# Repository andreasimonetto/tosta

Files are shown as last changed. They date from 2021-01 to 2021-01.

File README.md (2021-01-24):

# Tosta

Tosta is a **low-power terminal interface module** built around the [STM32G030](docs/STM32G0x0.pdf) microcontroller. The module features:

- 48x84 monochrome pixel matrix (Nokia 5510 LCD using [PCD8544](docs/PCD8544.pdf) controller)
- configurable dimmable backlight
- configurable display standby timer
- a rotary encoder with central switch
- a D-Pad joystick with central switch
- 4 tactile switches
- a speaker
- an UART interface @ 115200 baud/s
- an I2C slave interface @ 400KHz (address 0x7D)
- 150uA consumption in standby mode

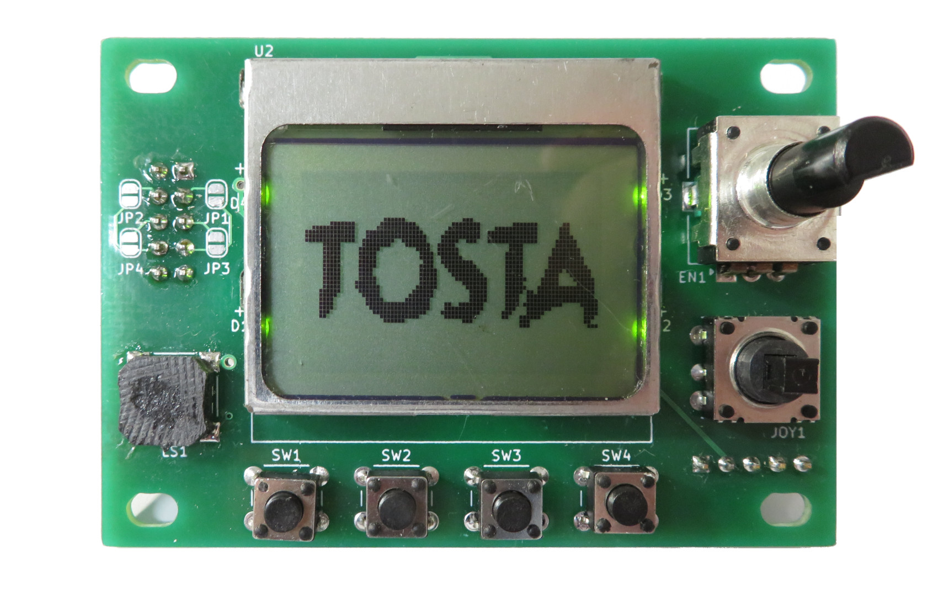
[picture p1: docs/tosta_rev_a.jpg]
Board


## User guide

The main communication interface (characters based) is UART @ 115200 baud/s.
I2C (binary based) is used for fast display update among other things.

### UART Inputs

When the module receive an input, it send a corresponding command character as
follows:

Event                        | Hex  | Char
---------------------------- | ---- | ----
SW1 pressed                  | 0x41 | A
SW1 released                 | 0x61 | a
SW2 pressed                  | 0x42 | B
SW2 released                 | 0x62 | b
SW3 pressed                  | 0x43 | C
SW3 released                 | 0x63 | c
SW4 pressed                  | 0x44 | D
SW4 released                 | 0x64 | d
D-Pad button pressed         | 0x45 | E
D-Pad button released        | 0x65 | e
D-Pad left pressed           | 0x46 | F
D-Pad left released          | 0x66 | f
D-Pad right pressed          | 0x47 | G
D-Pad right released         | 0x67 | g
D-Pad up pressed             | 0x48 | H
D-Pad up released            | 0x68 | h
D-Pad down pressed           | 0x49 | I
D-Pad down released          | 0x69 | i
Encoder button pressed       | 0x4A | J
Encoder button released      | 0x6A | j
Encoder turn clockwise       | 0x2B | +
Encoder turn anti-clockwise  | 0x2D | -

### Display matrix

The display matrix comprises 84 horizontal by 48 vertical pixels.
Each individual pixel is either *on* (1) or *off* (0) which corresponds to the
status of a single bit. Individual bits are grouped into bytes, representing
a sub-column of 8 pixels.

Bytes endianess

The next byte is the nearby sub-column, on the right side. The display
frame buffer contains a total 504 bytes: 84 for the upper sub-columns, 84 for
the next ones and so on, for a total of 6 (84x6 bytes, row-major ordering).

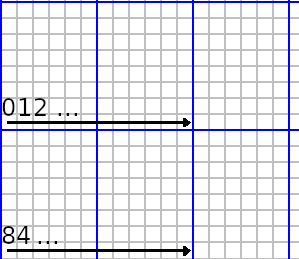
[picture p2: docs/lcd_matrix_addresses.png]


Characters are a logical subdivision into a 14x6 matrix, in which each cell is
a 6x8 pixels sub-matrix (see blue lines).

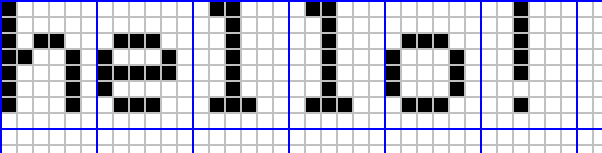
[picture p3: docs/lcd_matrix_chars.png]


```
h   0x7f 0x08 0x04 0x04 0x78 0x00
e   0x38 0x54 0x54 0x54 0x18 0x00
l   0x00 0x41 0x7f 0x40 0x00 0x00
l   0x00 0x41 0x7f 0x40 0x00 0x00
o   0x38 0x44 0x44 0x44 0x38 0x00
!   0x00 0x00 0x5f 0x00 0x00 0x00
```

### UART outputs

Writing characters works as usual on a *tty* device, using standard ASCII
encoding (printable characters from 0x20 up to 0x7F). There are few special
characters:

- `\a` (bell): play a C4 note from the speaker for 250ms
- `\b` (backspace): delete the last displayed character
- `\n` (line feed): newline
- `\f` (form feed): clear screen
- `\r` (carriage return): move cursor to the beginning of the current line

The user can also add non-standard custom characters (from 0x80 to 0xFF) using
[parametric escape sequences](#escape-sequences).

#### Escape sequences

Escape sequences are used to obtain special behaviours. In order to start
an escape sequence, the special character `\e` (or `\x1B` or `\033`) must be
used.

Basic sequences are:

Sequence | Effect
-------- | ---------------------------------
`\es`    | Put the display in standby
`\ew`    | Wake up the display from standby
`\el`    | Display an awesome logo

Advanced sequences allow passing numerical parameters, and they're started
using `\e[` (i.e. `\x1B[` or `\033[`).

Sequence                           | Effect
-----------------                  | ------------------------------------------------------------
`\e[`N`b`                          | Set display backlight brightness, with *N in [0, 127]*
`\e[`N`,`A`,`B`,`C`,`D`,`E`,`F`c`  | Set user character *N*, specifying bytes in the character sub-matrix from left to right (*N in [128, 255]*; *A,B,C,D,E,F in [0, 255])*
`\e[`F`,`T`p`                      | Play sound (immediate) having frequency *F* for *T* milliseconds
`\e[`F`,`T`q`                      | Enqueue sound playing with frequency *F* for *T* milliseconds
`\e[`T`s`                          | Set the display standby timer in *T* milliseconds (0 to disable standby)
`\e[`X`,`Y`z`                      | Set cursor position to *X in [0, 13]* and *Y in [0, 5]*

##### Example

```sh
stty -F /dev/ttyUSB0 115200
echo -ne "\e[128,12,30,60,30,12,0c" >>/dev/ttyUSB0
echo -ne "\f\x80\x80\x80\x80\x80\x80\x80\x80\x80\x80\x80\x80\x80\x80Frere Jacques\n\x80\x80\x80\x80\x80\x80\x80\x80\x80\x80\x80\x80\x80\x80" >>/dev/ttyUSB0
echo -ne "\e[1047,500q\e[1175,500q\e[1319,500q\e[1047,500q\e[1047,500q\e[1175,500q\e[1319,500q\e[1047,500q\e[1319,500q\e[1397,500q\e[1568,500q\e[0,500q\e[1319,500q\e[1397,500q\e[1568,500q" >>/dev/ttyUSB0
```

### I²C

- Send 1 byte to address 0x7D for command (0), necessary to wake the MCU from stop mode nicely
- Send the framebuffer (504 bytes) to address 0x7D
- ...

## Firmware

Firmware is written using the [STM32 Cube IDE](https://www.st.com/en/development-tools/stm32cubeide.html).

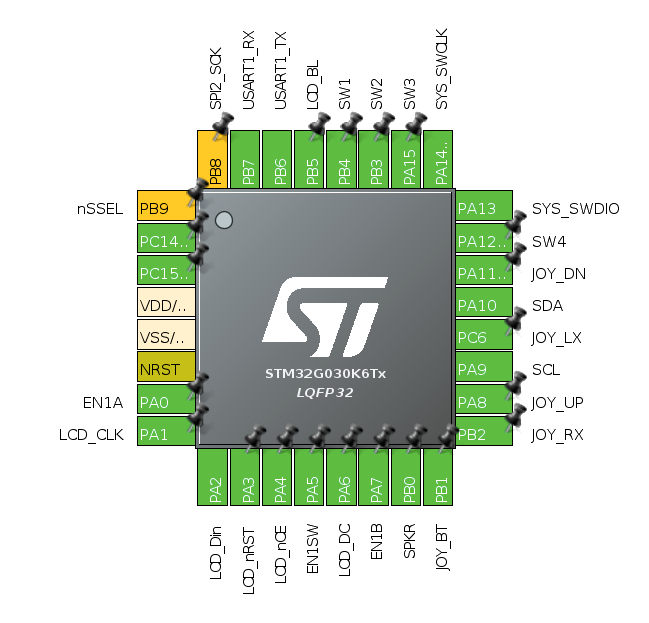
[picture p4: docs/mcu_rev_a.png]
MCU pinout


### Peripherals assignment:

- TIM1: speaker PWM
- TIM3: LCD backlight PWM
- TIM14: Inputs debounce
- SPI1+DMA: LCD data output
- UART: main serial communication interface
- I2C1: secondary communication interface (slave)

## Hardware

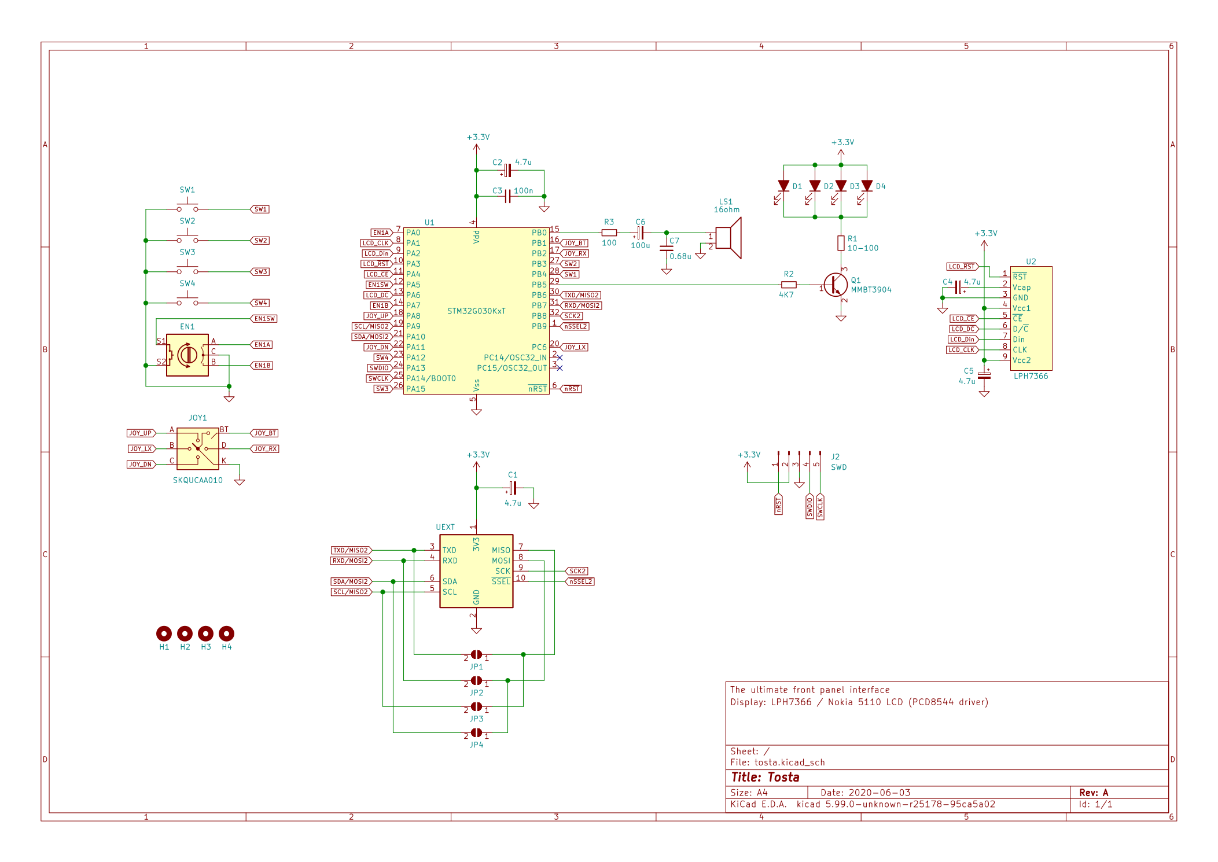
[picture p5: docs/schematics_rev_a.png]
Schematics


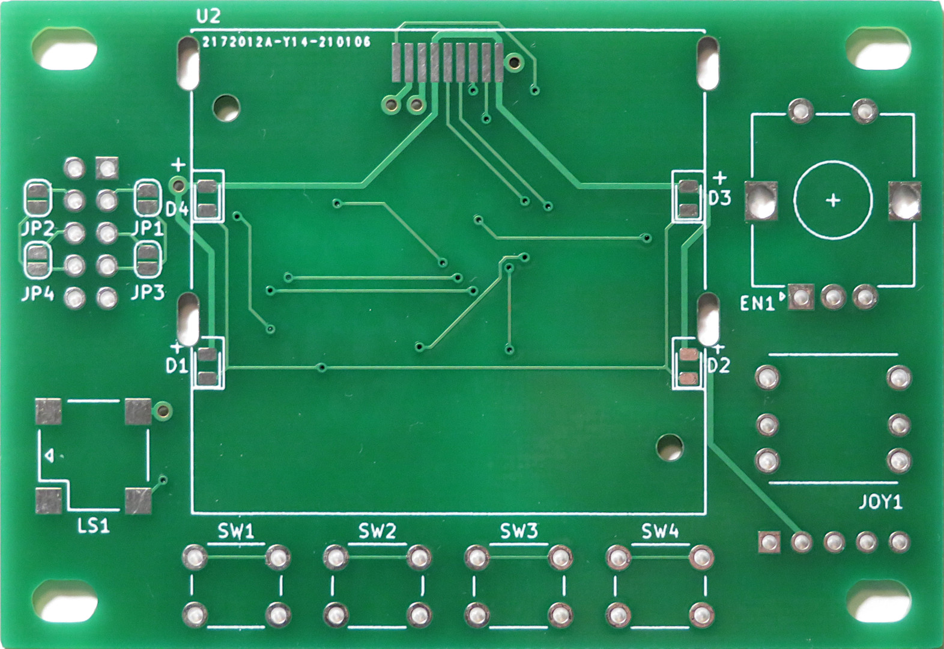
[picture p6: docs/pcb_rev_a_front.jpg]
PCB front


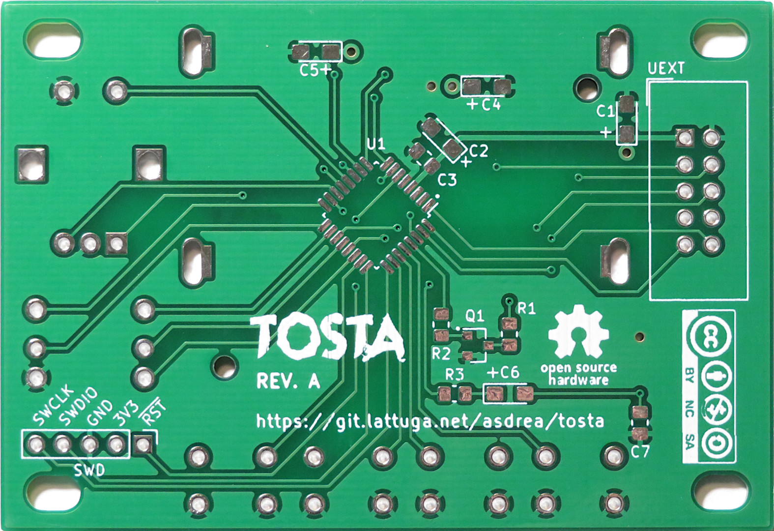
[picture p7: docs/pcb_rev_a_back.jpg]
PCB back


## Trivia

```C
0x7D == ('t' ^ 'o' ^ 's' ^ 't' ^ 'a')
```

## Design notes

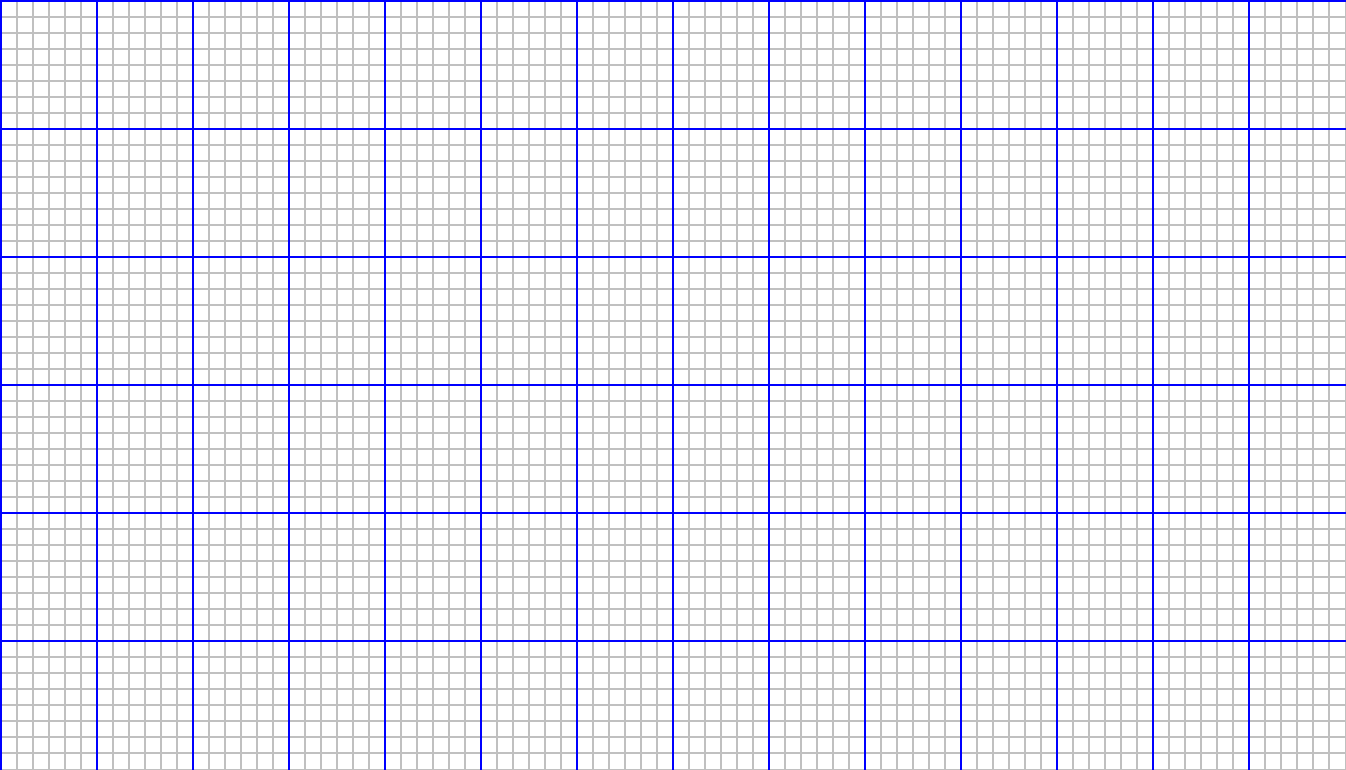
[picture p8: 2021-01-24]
docs/lcd_matrix_empty.png

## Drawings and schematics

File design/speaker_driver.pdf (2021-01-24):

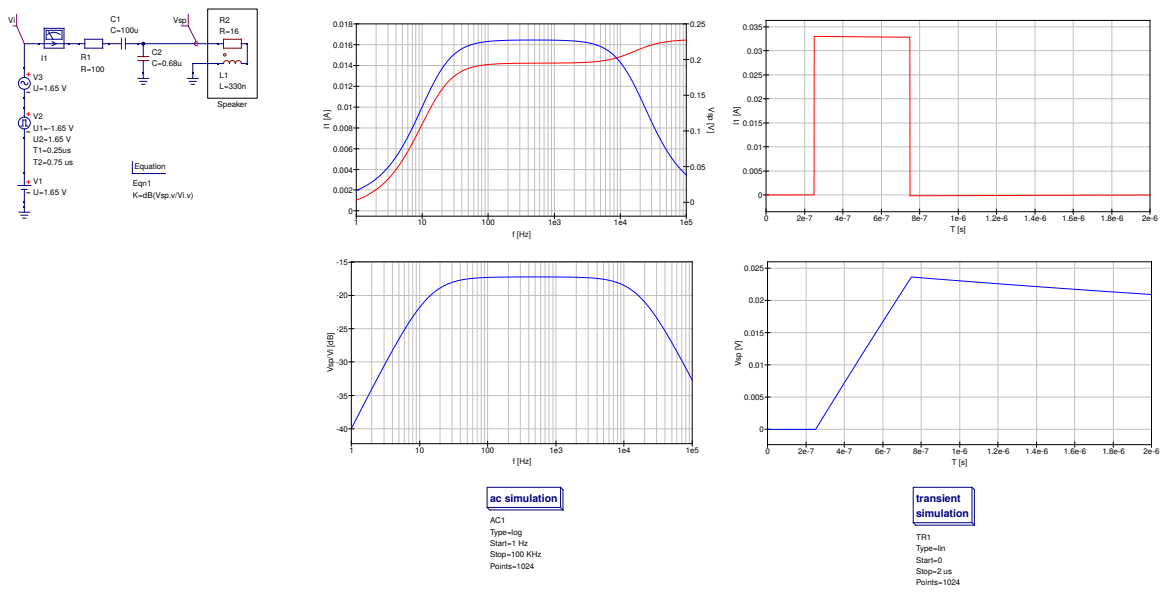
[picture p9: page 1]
Equation Eqn1 K=dB(Vsp.v/Vi.v) V2U1=-1.65 V U2=1.65 V T1=0.25us T2=0.75 us V1U=1.65 V; transient simulation TR1 Type=lin Start=0 Stop=2 us Points=1024 ac simulation AC1 Type=log Start=1 Hz Stop=100 KHz Points=1024 R1 R=100 Vi; Vsp; Speaker; Vsp [V] 1; f [Hz] Vsp/Vi [dB]; T [s] Vsp [V]

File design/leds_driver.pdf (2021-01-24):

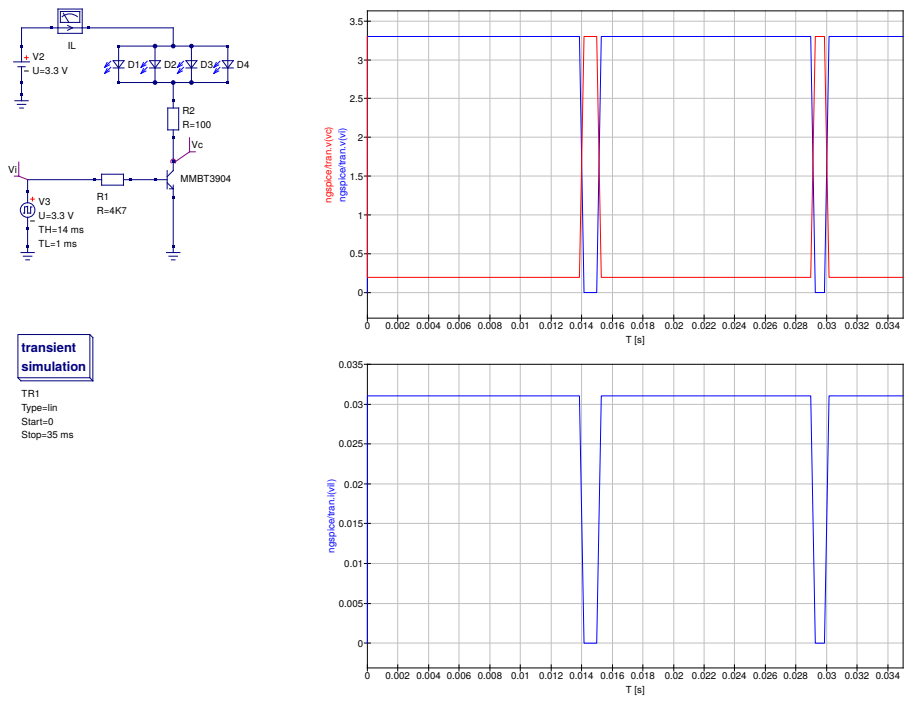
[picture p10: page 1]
transient simulation; Stop=35 ms; MMBT3904

ngspice/tran.v(vi) ngspice/tran.v(vc) 0 0.002 0.004 0.006 0.008 0.01 0.012 0.014 0.016 0.018 0.02 0.022 0.024 0.026 0.028 0.03 0.032 0.034

Type=lin Start=0

ngspice/tran.i(vil)

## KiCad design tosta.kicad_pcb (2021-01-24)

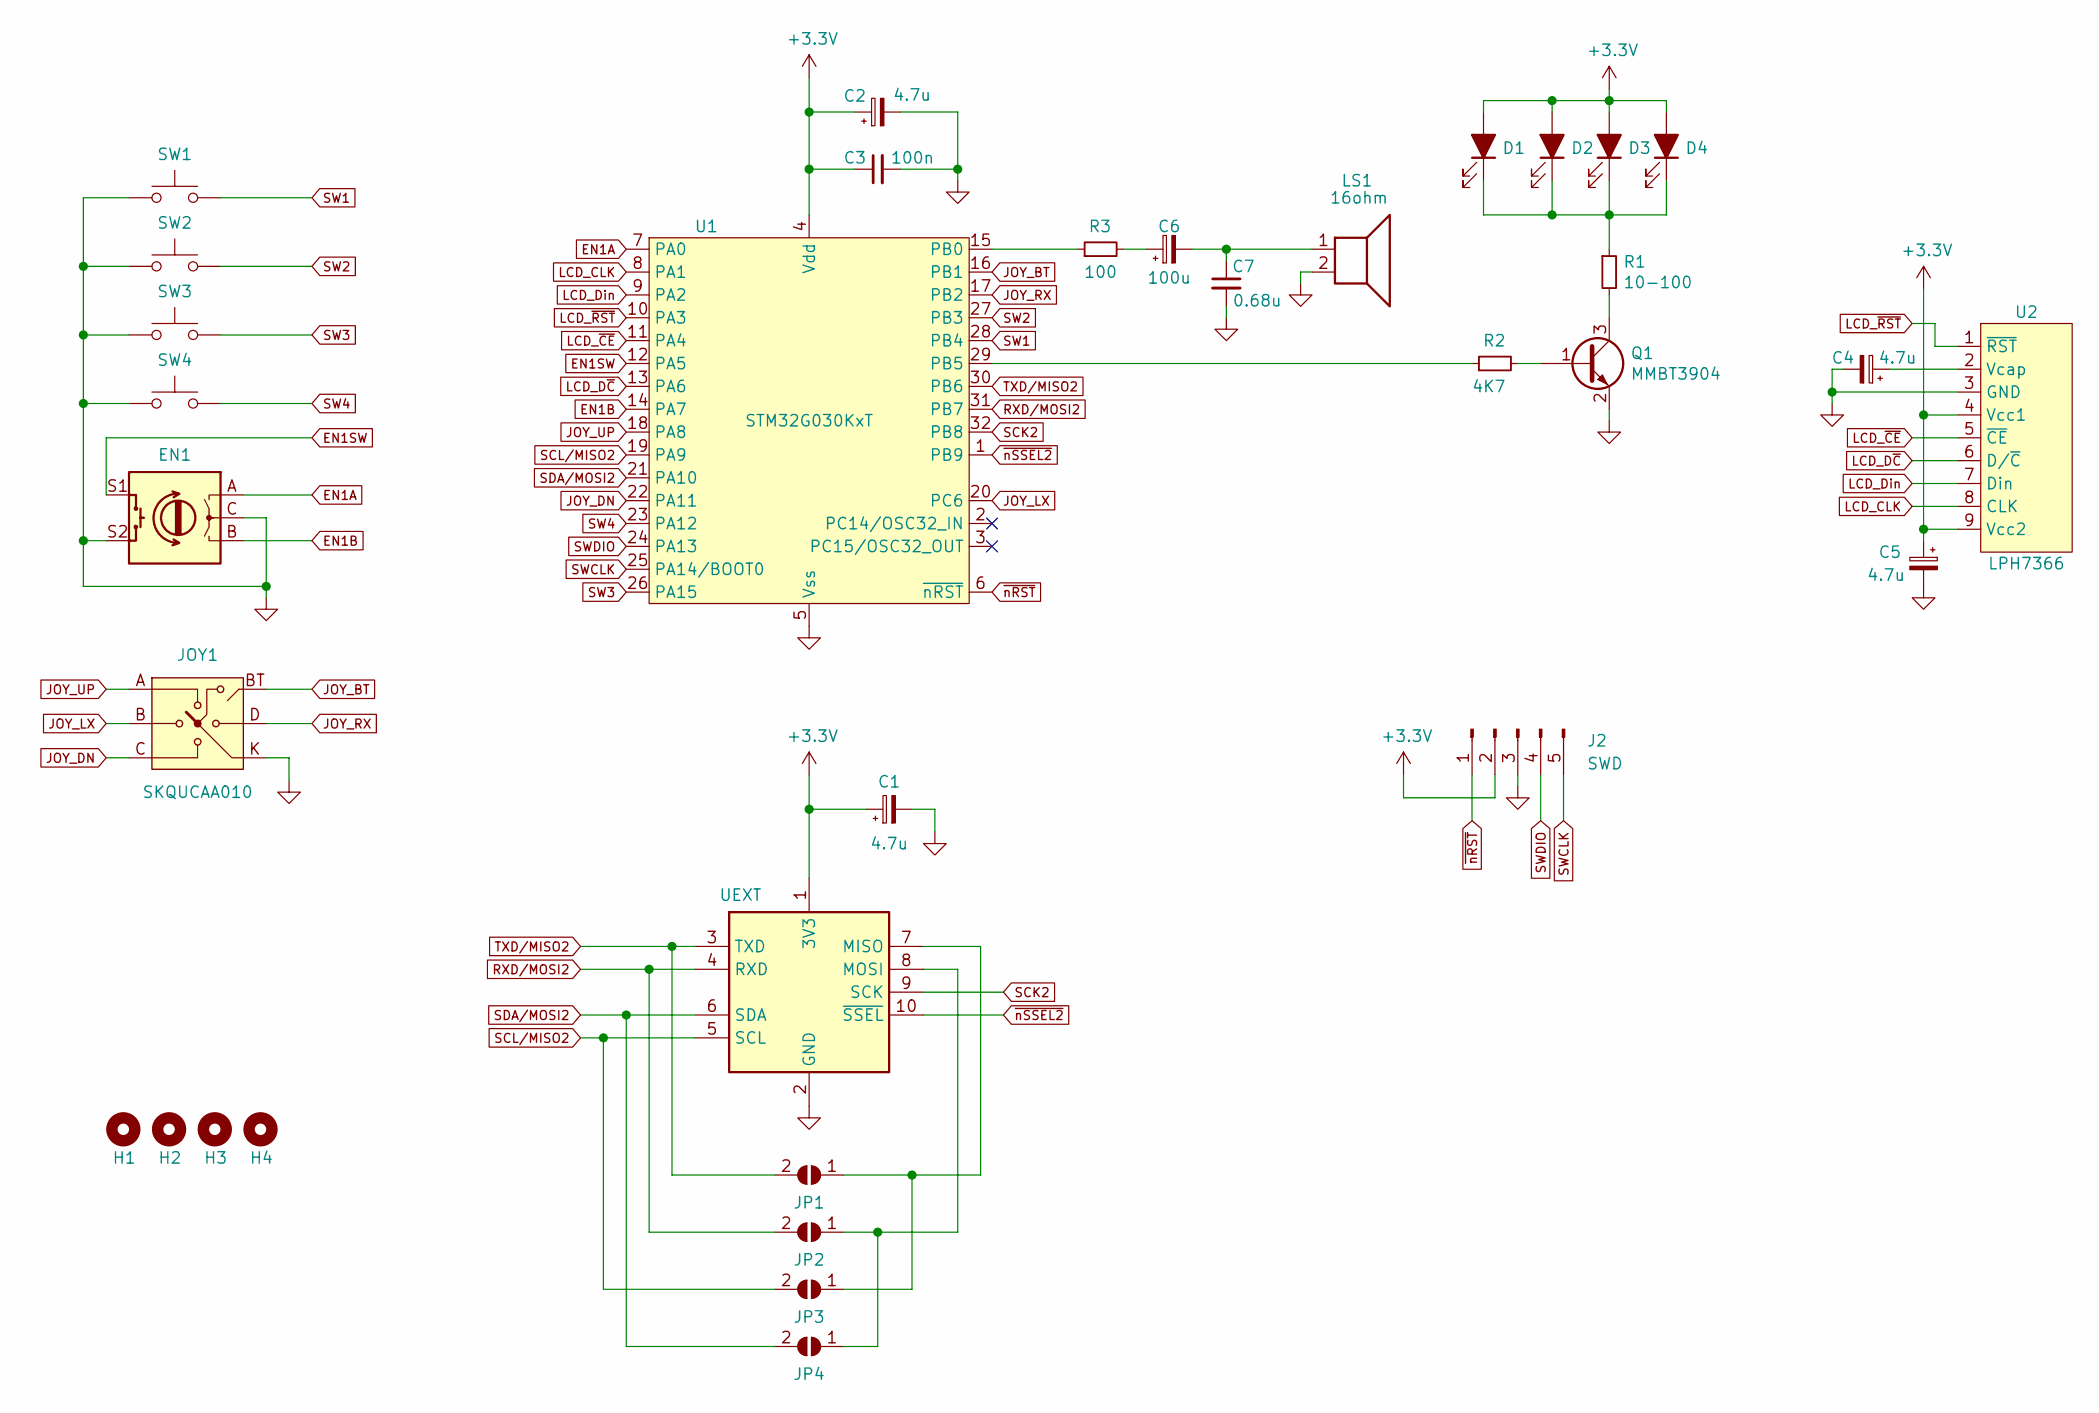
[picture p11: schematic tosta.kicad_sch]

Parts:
C1, C2, C4, C5: 4.7u; CP_EIA-3216-12_Kemet-S_Pad1.58x1.35mm_HandSolder
C3: 100n; C_0805_2012Metric_Pad1.15x1.40mm_HandSolder
C6: 100u; CP_EIA-3216-12_Kemet-S_Pad1.58x1.35mm_HandSolder
C7: 0.68u; C_0805_2012Metric_Pad1.18x1.45mm_HandSolder
D1, D2, D3, D4: LED_ALT; LED_0805_2012Metric
EN1: Rotary_Encoder_Switch; RotaryEncoder_Alps_EC12E-Switch_Vertical_H20mm
H1, H2, H3, H4: MountingHole; M3_ISO7380
J2: SWD; PinHeader_1x05_P2.54mm_Vertical
JOY1: SKQUCAA010
JP1, JP2, JP3, JP4: SolderJumper_2_Open; SolderJumper-2_P1.3mm_Open_RoundedPad1.0x1.5mm
LS1: 16ohm; KY_BUZ
Q1: MMBT3904; SOT-23
R1: 10-100; R_0805_2012Metric_Pad1.15x1.40mm_HandSolder
R2: 4K7; R_0805_2012Metric_Pad1.15x1.40mm_HandSolder
R3: 100; R_0805_2012Metric_Pad1.20x1.40mm_HandSolder
SW1, SW2, SW3, SW4: SW_Push; SW_PUSH_6mm_H4.3mm
U1: STM32G030KxT; LQFP-32_7x7mm_P0.8mm
U2: LPH7366
UEXT: UEXT; IDC-Header_2x05_P2.54mm_Vertical

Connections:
+3V3: C1.1, C2.1, C3.1, C5.1, D1.2 (A), D2.2 (A), D3.2 (A), D4.2 (A), J2.2, U1.4 (Vdd), U2.4 (Vcc1), U2.9 (Vcc2), UEXT.1 (3V3)
EN1A: EN1.A, U1.7 (PA0)
EN1B: EN1.B, U1.14 (PA7)
EN1SW: EN1.S1, U1.12 (PA5)
GND: C1.2, C2.2, C3.2, C4.2, C5.2, C7.2, EN1.C, EN1.S2, J2.3, JOY1.K, LS1.2, Q1.2 (E), SW1.2, SW2.2, SW3.2, SW4.2, U1.5 (Vss), U2.3 (GND), UEXT.2 (GND)
JOY_BT: JOY1.BT, U1.16 (PB1)
JOY_DN: JOY1.C, U1.22 (PA11)
JOY_LX: JOY1.B, U1.20 (PC6)
JOY_RX: JOY1.D, U1.17 (PB2)
JOY_UP: JOY1.A, U1.18 (PA8)
LCD_CLK: U1.8 (PA1), U2.8 (CLK)
LCD_Din: U1.9 (PA2), U2.7 (Din)
LCD_D~C: U1.13 (PA6), U2.6 (D/~C)
LCD_~CE: U1.11 (PA4), U2.5 (~CE)
LCD_~RST: U1.10 (PA3), U2.1 (~RST)
unnamed: C4.1, U2.2 (Vcap)
unnamed: C6.1, R3.2
unnamed: C6.2, C7.1, LS1.1
unnamed: D1.1 (K), D2.1 (K), D3.1 (K), D4.1 (K), R1.1
unnamed: JP1.1 (A), JP3.1 (A), UEXT.7 (MISO)
unnamed: JP2.1 (A), JP4.1 (A), UEXT.8 (MOSI)
unnamed: Q1.1 (B), R2.2
unnamed: Q1.3 (C), R1.2
unnamed: R2.1, U1.29 (PB5)
unnamed: R3.1, U1.15 (PB0)
RXD/MOSI2: JP2.2 (B), U1.31 (PB7), UEXT.4 (RXD)
SCK2: U1.32 (PB8), UEXT.9 (SCK)
SCL/MISO2: JP3.2 (B), U1.19 (PA9), UEXT.5 (SCL)
SDA/MOSI2: JP4.2 (B), U1.21 (PA10), UEXT.6 (SDA)
SW1: SW1.1, U1.28 (PB4)
SW2: SW2.1, U1.27 (PB3)
SW3: SW3.1, U1.26 (PA15)
SW4: SW4.1, U1.23 (PA12)
SWCLK: J2.5, U1.25 (PA14/BOOT0)
SWDIO: J2.4, U1.24 (PA13)
TXD/MISO2: JP1.2 (B), U1.30 (PB6), UEXT.3 (TXD)
~nRST: J2.1, U1.6 (~nRST)
~nSSEL2: U1.1 (PB9), UEXT.10 (~SSEL)

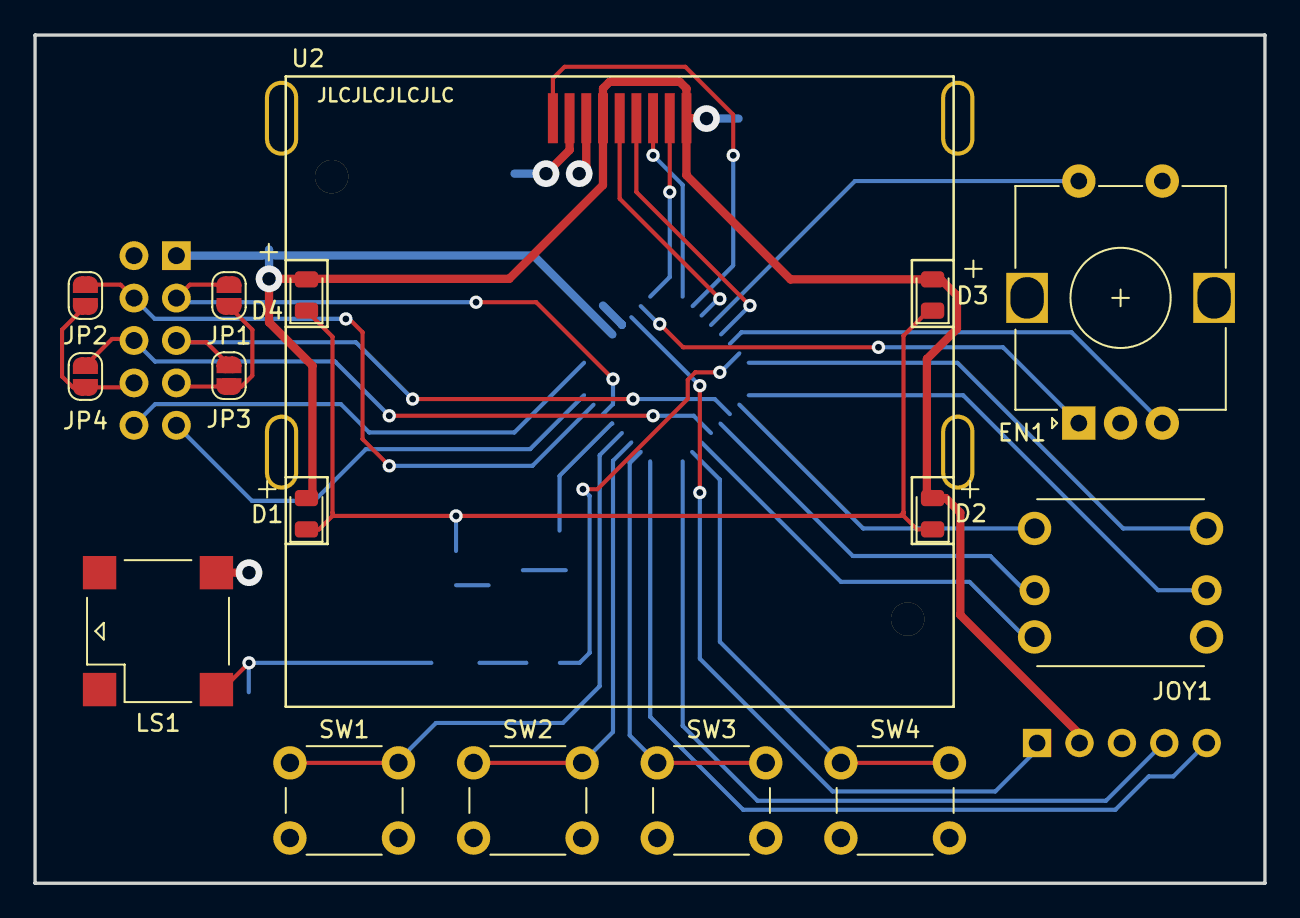
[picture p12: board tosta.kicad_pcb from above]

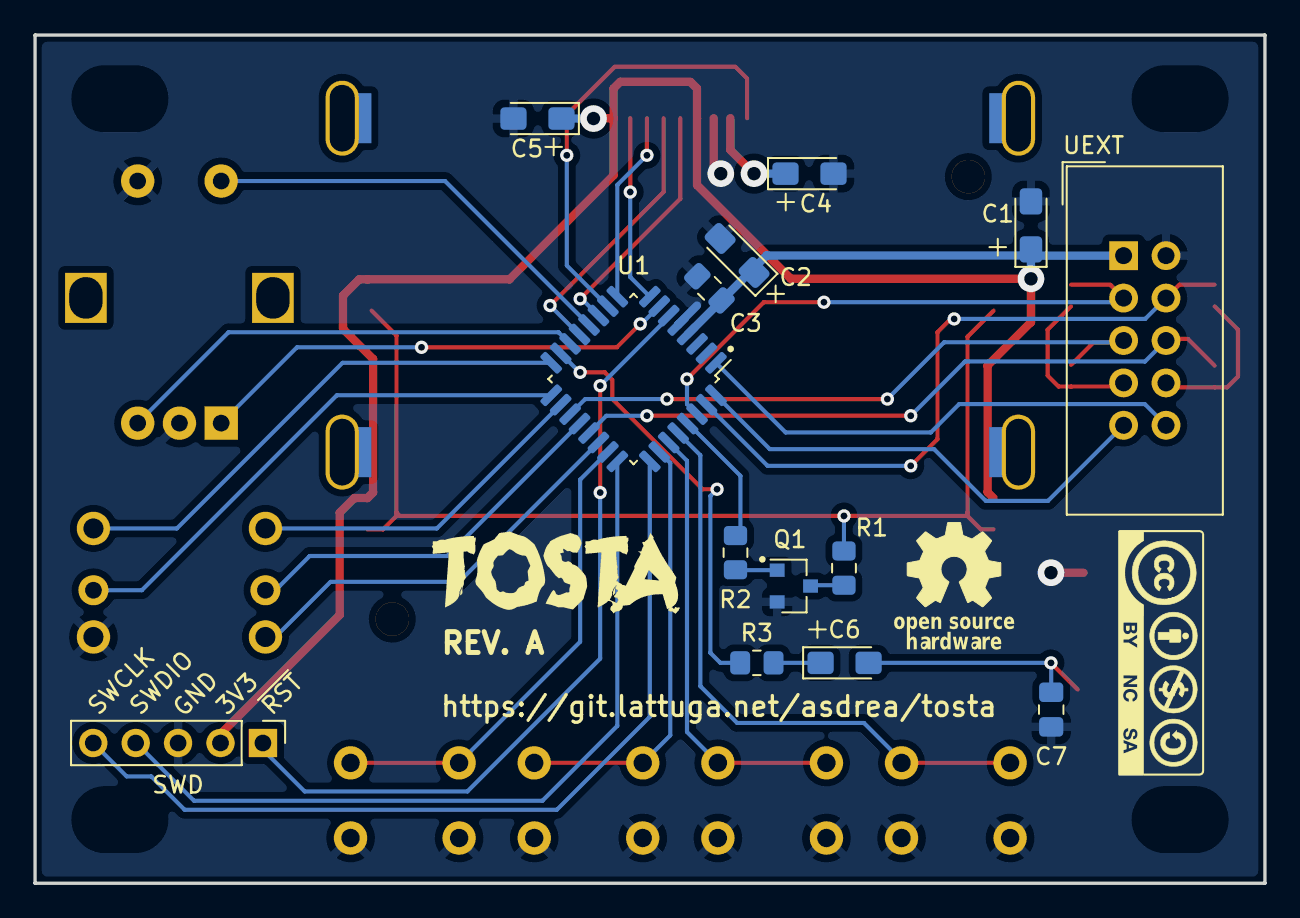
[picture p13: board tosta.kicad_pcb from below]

Board: 2 copper layers, 73.7 x 50.8 mm, 37 parts (17 on the bottom side), 38 nets.

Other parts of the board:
CC_BYNCSA: G***; cc_byncsa
OSHW: G***; oshw
svg2mod: G***; logo

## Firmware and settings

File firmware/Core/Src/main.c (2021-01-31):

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
/* Includes ------------------------------------------------------------------*/
#include "main.h"

/* USER CODE BEGIN Includes */
#include "lcd.h"
#include "lcd_char.h"
#include "speaker.h"
#include "buttons.h"
/* USER CODE END Includes */

I2C_HandleTypeDef hi2c1;

SPI_HandleTypeDef hspi1;
DMA_HandleTypeDef hdma_spi1_tx;

TIM_HandleTypeDef htim1;
TIM_HandleTypeDef htim3;
TIM_HandleTypeDef htim14;

UART_HandleTypeDef huart1;

/* USER CODE BEGIN PV */

typedef enum {
	I2C_CMD_WRITE_FRAMEBUF,
} i2c_cmd_t;

static volatile uint8_t char_in;
static volatile uint8_t to_blit = 0;
static volatile uint32_t uart_timeout_ticks = 0;
static volatile i2c_cmd_t i2c_cmd;
volatile uint8_t i2c_idle = 1;
/* USER CODE END PV */

void SystemClock_Config(void);
static void MX_GPIO_Init(void);
static void MX_DMA_Init(void);
static void MX_I2C1_Init(void);
static void MX_SPI1_Init(void);
static void MX_TIM3_Init(void);
static void MX_TIM1_Init(void);
static void MX_USART1_UART_Init(void);
static void MX_TIM14_Init(void);
/* USER CODE BEGIN 0 */
void on_button_pressed(button_t b)
{
	uint8_t d = 'A' + b;
	HAL_UART_Transmit_IT(&huart1, &d, 1);
}

void on_button_released(button_t b)
{
	uint8_t d = 'a' + b;
	HAL_UART_Transmit_IT(&huart1, &d, 1);
}

void on_encoder_change(int8_t sign)
{
	uint8_t d = (sign > 0 ? '+' : '-');
	HAL_UART_Transmit_IT(&huart1, &d, 1);
}

void HAL_UART_RxCpltCallback(UART_HandleTypeDef *huart)
{
	if(huart == &huart1) {
		HAL_ResumeTick();
		LCD_char_inject(char_in);
		uart_timeout_ticks = 5;
		HAL_UART_Receive_IT(&huart1, (void*)&char_in, 1);
	}
}

void HAL_I2C_SlaveRxCpltCallback(I2C_HandleTypeDef* hi2c)
{
	if(hi2c == &hi2c1) {
		if(i2c_idle) {
			i2c_idle = 0;
			switch(i2c_cmd) {
				case I2C_CMD_WRITE_FRAMEBUF:
					HAL_I2C_Slave_Receive_IT(&hi2c1, (void*)lcd_framebuf, LCD_FRAMEBUF_SIZE);
					break;
				default:
					i2c_idle = 1;
					HAL_I2C_Slave_Receive_IT(&hi2c1, (void*)&i2c_cmd, 1);
					break;
			}
		}
		else {
			switch(i2c_cmd) {
				case I2C_CMD_WRITE_FRAMEBUF:
					to_blit = 1;
					break;
			}
			HAL_I2C_Slave_Receive_IT(&hi2c1, (void*)&i2c_cmd, 1);
			i2c_idle = 1;
		}

		HAL_ResumeTick();
	}
}

void HAL_IncTick(void)
{
	uwTick += uwTickFreq;
	speaker_standby_tick(uwTickFreq);
	LCD_standby_tick(uwTickFreq);
	if(uart_timeout_ticks > uwTickFreq)
		uart_timeout_ticks -= uwTickFreq;
	else {
		if(uart_timeout_ticks)
			to_blit = 1;
		uart_timeout_ticks = 0;
	}
}
/* USER CODE END 0 */

/**
  * @brief  The application entry point.
  * @retval int
  */
int main(void)
{
  /* MCU Configuration--------------------------------------------------------*/

  /* Reset of all peripherals, Initializes the Flash interface and the Systick. */
  HAL_Init();

  /* Configure the system clock */
  SystemClock_Config();

  /* Initialize all configured peripherals */
  MX_GPIO_Init();
  MX_DMA_Init();
  MX_I2C1_Init();
  MX_SPI1_Init();
  MX_TIM3_Init();
  MX_TIM1_Init();
  MX_USART1_UART_Init();
  MX_TIM14_Init();
  /* USER CODE BEGIN 2 */

#if (ENABLE_I2C == 0)
  HAL_I2C_DeInit(&hi2c1);
#endif

  speaker_init();
  LCD_init();

#ifdef DEBUG
  HAL_DBGMCU_EnableDBGStopMode();
#else
  do {
	  GPIO_InitTypeDef GPIO_InitStruct = {0};

	  GPIO_InitStruct.Pin = GPIO_PIN_13;
	  GPIO_InitStruct.Mode = GPIO_MODE_OUTPUT_PP;
	  GPIO_InitStruct.Pull = GPIO_NOPULL;
	  GPIO_InitStruct.Speed = GPIO_SPEED_FREQ_LOW;
	  HAL_GPIO_Init(GPIOA, &GPIO_InitStruct);
	  HAL_GPIO_WritePin(GPIOA, GPIO_PIN_13, 0);

	  GPIO_InitStruct.Pin = GPIO_PIN_14;
	  GPIO_InitStruct.Mode = GPIO_MODE_OUTPUT_PP;
	  GPIO_InitStruct.Pull = GPIO_NOPULL;
	  GPIO_InitStruct.Speed = GPIO_SPEED_FREQ_LOW;
	  HAL_GPIO_Init(GPIOA, &GPIO_InitStruct);
	  HAL_GPIO_WritePin(GPIOA, GPIO_PIN_14, 0);
  } while(0);
#endif

  UART_WakeUpTypeDef uw = { UART_WAKEUP_ON_READDATA_NONEMPTY, 0, 0 };
  HAL_UARTEx_StopModeWakeUpSourceConfig(&huart1, uw);
  HAL_UARTEx_EnableStopMode(&huart1);
  HAL_UART_Receive_IT(&huart1, (void*)&char_in, 1);

  HAL_I2CEx_EnableWakeUp(&hi2c1);
  HAL_I2C_Slave_Receive_IT(&hi2c1, (void*)&i2c_cmd, 1);
  /* USER CODE END 2 */

  /* Infinite loop */
  /* USER CODE BEGIN WHILE */
  while(1)
  {
    /* USER CODE END WHILE */

    /* USER CODE BEGIN 3 */
	if(to_blit) {
		LCD_blit();
		to_blit = 0;
	}

	if(LCD_active() || speaker_playing() || buttons_debouncing() || uart_timeout_ticks || !i2c_idle)
		HAL_PWR_EnterSLEEPMode(PWR_LOWPOWERREGULATOR_ON, PWR_SLEEPENTRY_WFI);
	else {
		LCD_standby_enter();
		HAL_SuspendTick();
		HAL_PWR_EnterSTOPMode(PWR_LOWPOWERREGULATOR_ON, PWR_STOPENTRY_WFI);
		HAL_ResumeTick();
	}
  }
  /* USER CODE END 3 */
}

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


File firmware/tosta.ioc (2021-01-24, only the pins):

Mcu.UserName=STM32G030K6Tx
PA0.GPIO_Label=EN1A
PA0.Signal=GPXTI0
PA1.GPIO_Label=LCD_CLK
PA1.Signal=SPI1_SCK
PA10.GPIO_Label=SDA
PA10.Signal=I2C1_SDA
PA13.Signal=SYS_SWDIO
PA14-BOOT0.Signal=SYS_SWCLK
PA15.GPIO_Label=SW3
PA15.Signal=GPXTI15
PA2.GPIO_Label=LCD_Din
PA2.Signal=SPI1_MOSI
PA3.GPIO_Label=LCD_nRST
PA3.Signal=GPIO_Output
PA4.GPIO_Label=LCD_nCE
PA4.Signal=SPI1_NSS
PA5.GPIO_Label=EN1SW
PA5.Signal=GPXTI5
PA6.GPIO_Label=LCD_DC
PA6.Signal=GPIO_Output
PA7.GPIO_Label=EN1B
PA7.Signal=GPXTI7
PA8.GPIO_Label=JOY_UP
PA8.Signal=GPXTI8
PA9.GPIO_Label=SCL
PA9.Signal=I2C1_SCL
PB0.GPIO_Label=SPKR
PB0.Signal=TIM1_CH2N
PB1.GPIO_Label=JOY_BT
PB1.Signal=GPXTI1
PB2.GPIO_Label=JOY_RX
PB2.Signal=GPXTI2
PB3.GPIO_Label=SW2
PB3.Signal=GPXTI3
PB4.GPIO_Label=SW1
PB4.Signal=GPXTI4
PB5.GPIO_Label=LCD_BL
PB5.Signal=S_TIM3_CH2
PB6.Signal=USART1_TX
PB7.Signal=USART1_RX
PB8.Signal=SPI2_SCK
PB9.GPIO_Label=nSSEL
PB9.Signal=SPI2_NSS
PC6.GPIO_Label=JOY_LX
PC6.Signal=GPXTI6

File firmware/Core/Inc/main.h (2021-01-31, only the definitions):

#define ENABLE_I2C 0
#define nSSEL_Pin GPIO_PIN_9
#define nSSEL_GPIO_Port GPIOB
#define EN1A_Pin GPIO_PIN_0
#define EN1A_GPIO_Port GPIOA
#define EN1A_EXTI_IRQn EXTI0_1_IRQn
#define LCD_CLK_Pin GPIO_PIN_1
#define LCD_CLK_GPIO_Port GPIOA
#define LCD_Din_Pin GPIO_PIN_2
#define LCD_Din_GPIO_Port GPIOA
#define LCD_nRST_Pin GPIO_PIN_3
#define LCD_nRST_GPIO_Port GPIOA
#define LCD_nCE_Pin GPIO_PIN_4
#define LCD_nCE_GPIO_Port GPIOA
#define EN1SW_Pin GPIO_PIN_5
#define EN1SW_GPIO_Port GPIOA
#define EN1SW_EXTI_IRQn EXTI4_15_IRQn
#define LCD_DC_Pin GPIO_PIN_6
#define LCD_DC_GPIO_Port GPIOA
#define EN1B_Pin GPIO_PIN_7
#define EN1B_GPIO_Port GPIOA
#define EN1B_EXTI_IRQn EXTI4_15_IRQn
#define SPKR_Pin GPIO_PIN_0
#define SPKR_GPIO_Port GPIOB
#define JOY_BT_Pin GPIO_PIN_1
#define JOY_BT_GPIO_Port GPIOB
#define JOY_BT_EXTI_IRQn EXTI0_1_IRQn
#define JOY_RX_Pin GPIO_PIN_2
#define JOY_RX_GPIO_Port GPIOB
#define JOY_RX_EXTI_IRQn EXTI2_3_IRQn
#define JOY_UP_Pin GPIO_PIN_8
#define JOY_UP_GPIO_Port GPIOA
#define JOY_UP_EXTI_IRQn EXTI4_15_IRQn
#define SCL_Pin GPIO_PIN_9
#define SCL_GPIO_Port GPIOA
#define JOY_LX_Pin GPIO_PIN_6
#define JOY_LX_GPIO_Port GPIOC
#define JOY_LX_EXTI_IRQn EXTI4_15_IRQn
#define SDA_Pin GPIO_PIN_10
#define SDA_GPIO_Port GPIOA
#define JOY_DN_Pin GPIO_PIN_11
#define JOY_DN_GPIO_Port GPIOA
#define JOY_DN_EXTI_IRQn EXTI4_15_IRQn
#define SW4_Pin GPIO_PIN_12
#define SW4_GPIO_Port GPIOA
#define SW4_EXTI_IRQn EXTI4_15_IRQn
#define SW3_Pin GPIO_PIN_15
#define SW3_GPIO_Port GPIOA
#define SW3_EXTI_IRQn EXTI4_15_IRQn
#define SW2_Pin GPIO_PIN_3
#define SW2_GPIO_Port GPIOB
#define SW2_EXTI_IRQn EXTI2_3_IRQn
#define SW1_Pin GPIO_PIN_4
#define SW1_GPIO_Port GPIOB
#define SW1_EXTI_IRQn EXTI4_15_IRQn
#define LCD_BL_Pin GPIO_PIN_5
#define LCD_BL_GPIO_Port GPIOB

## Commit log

2020-06-03 Repo initialized
    [tosta.kicad_pcb, tosta.kicad_sch]
2020-11-26 Added SWD header
    [tosta.kicad_pcb, tosta.kicad_sch]
2020-11-29 Updated speaker driver
    [tosta.kicad_pcb, tosta.kicad_sch]
2021-01-22 Basic peripherals and UART firmware
    [tosta Debug.cfg]
2021-01-24 Added basic I2C
2021-01-24 Imported design files
    [leds_driver.sch, speaker_driver.sch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]
2021-01-31 I2C off by default

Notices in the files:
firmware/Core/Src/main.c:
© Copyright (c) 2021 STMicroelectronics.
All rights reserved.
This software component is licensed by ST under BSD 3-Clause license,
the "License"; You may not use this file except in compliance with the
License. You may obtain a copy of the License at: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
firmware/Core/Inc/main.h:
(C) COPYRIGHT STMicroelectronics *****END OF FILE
